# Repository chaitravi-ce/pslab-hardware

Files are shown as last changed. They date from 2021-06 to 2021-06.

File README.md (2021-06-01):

# PSLab Hardware





This is a special branch `diff-img` where the changes made on all four layers relative to the immediate previous board is presented as a diff image.

## Current Layers

<details>
  <summary>External Layers</summary>

| Top | Bottom |
| --- | --- |
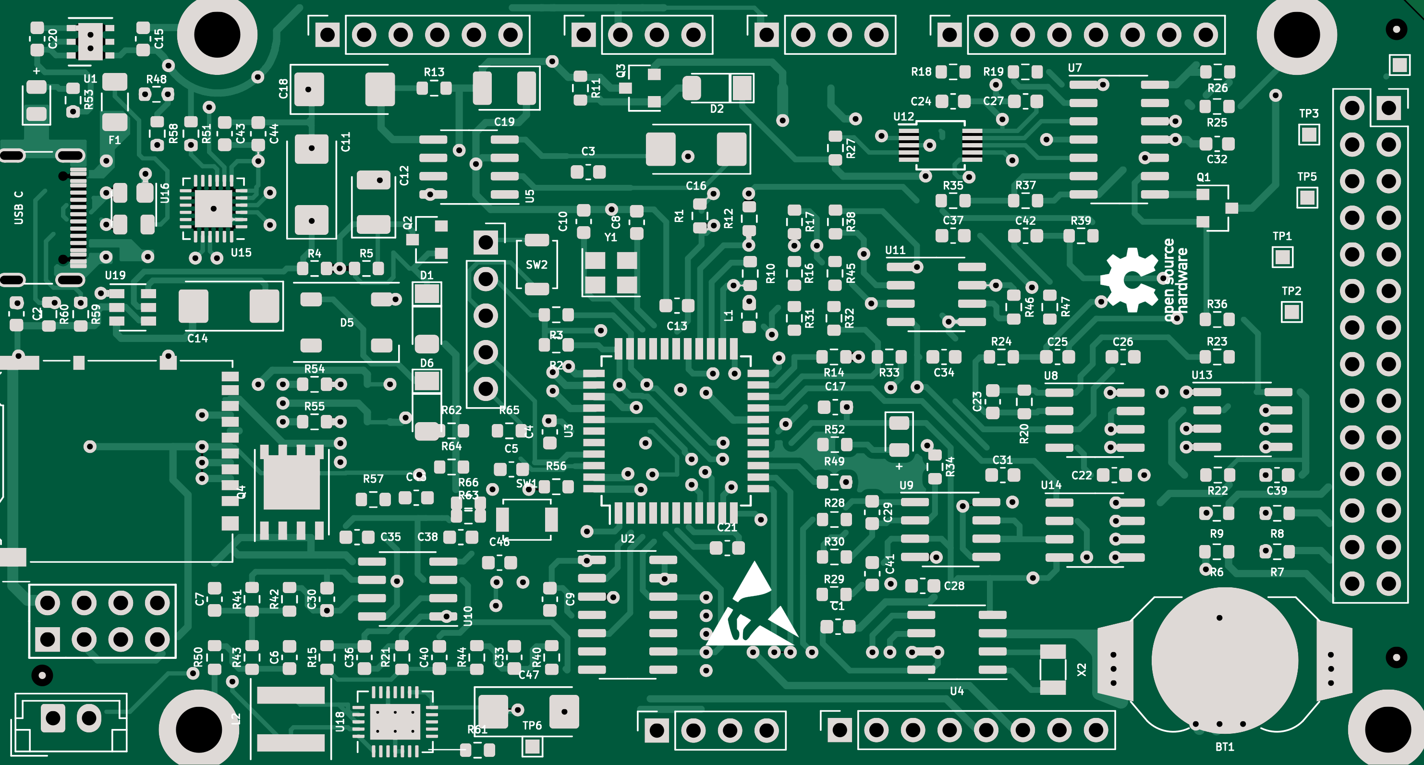
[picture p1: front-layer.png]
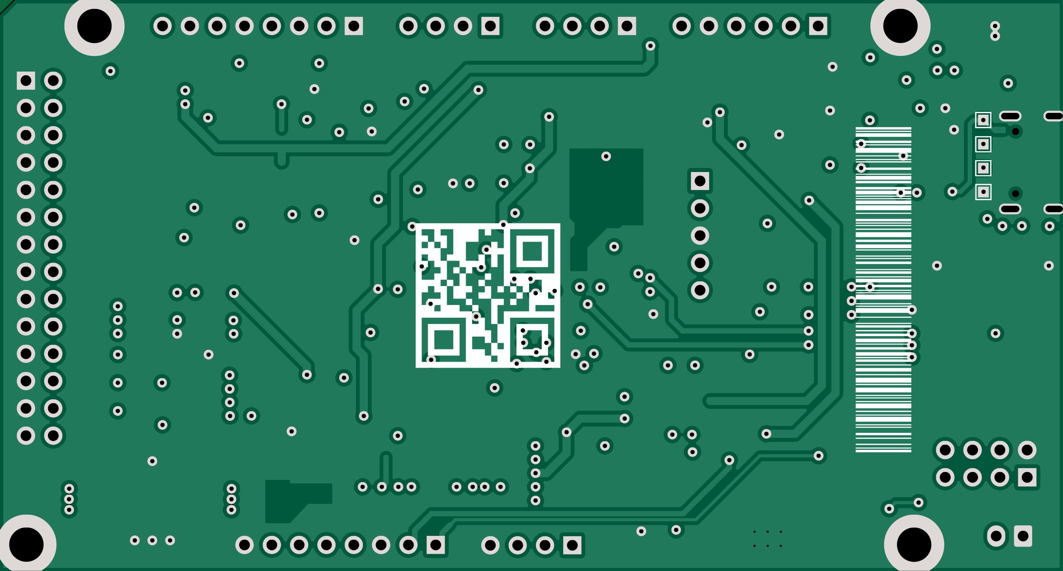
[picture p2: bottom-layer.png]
|  |  |
</details>

<details>
  <summary>Internal Layers</summary>

| Power | Signal |
| ----- | --- |
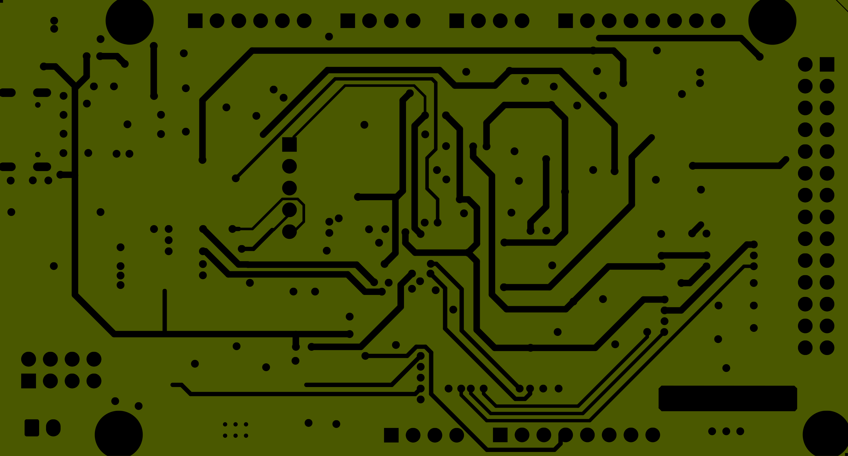
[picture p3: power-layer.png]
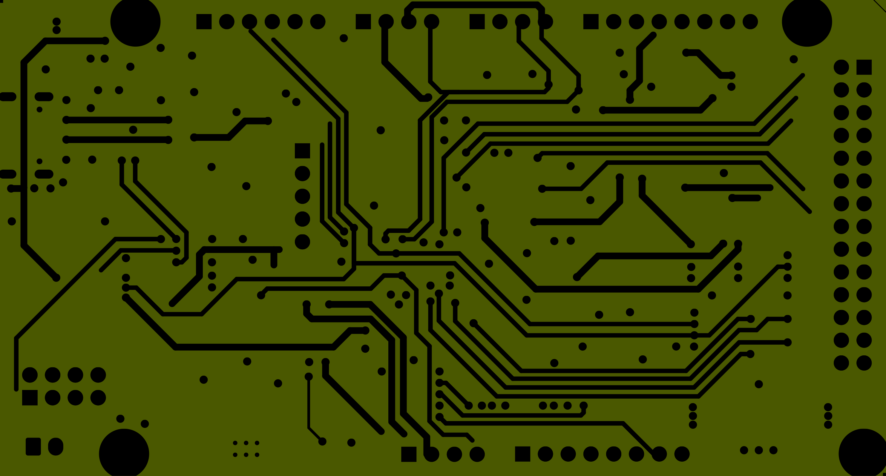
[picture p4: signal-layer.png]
|  |  |
</details>

## Legend

🟥 what the new board has

🟦 what the previous board had

## Schematic Changes
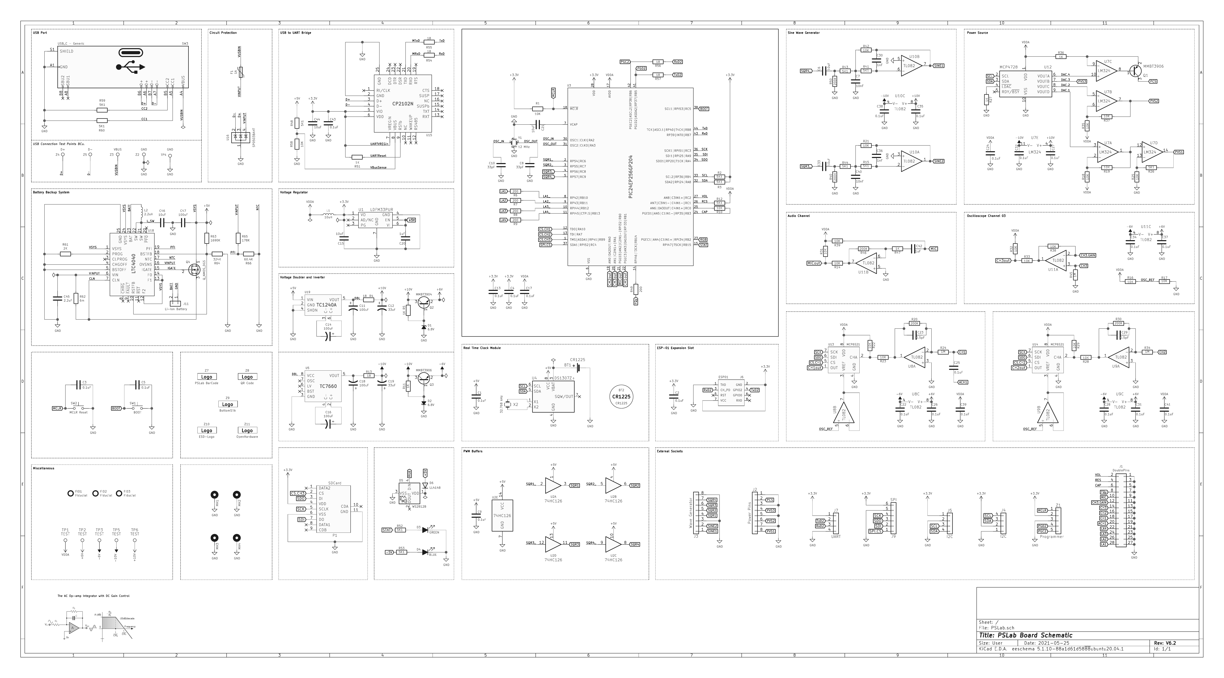
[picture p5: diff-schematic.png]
Schematic


## Board Changes
| Top Layer |
| ---------- |
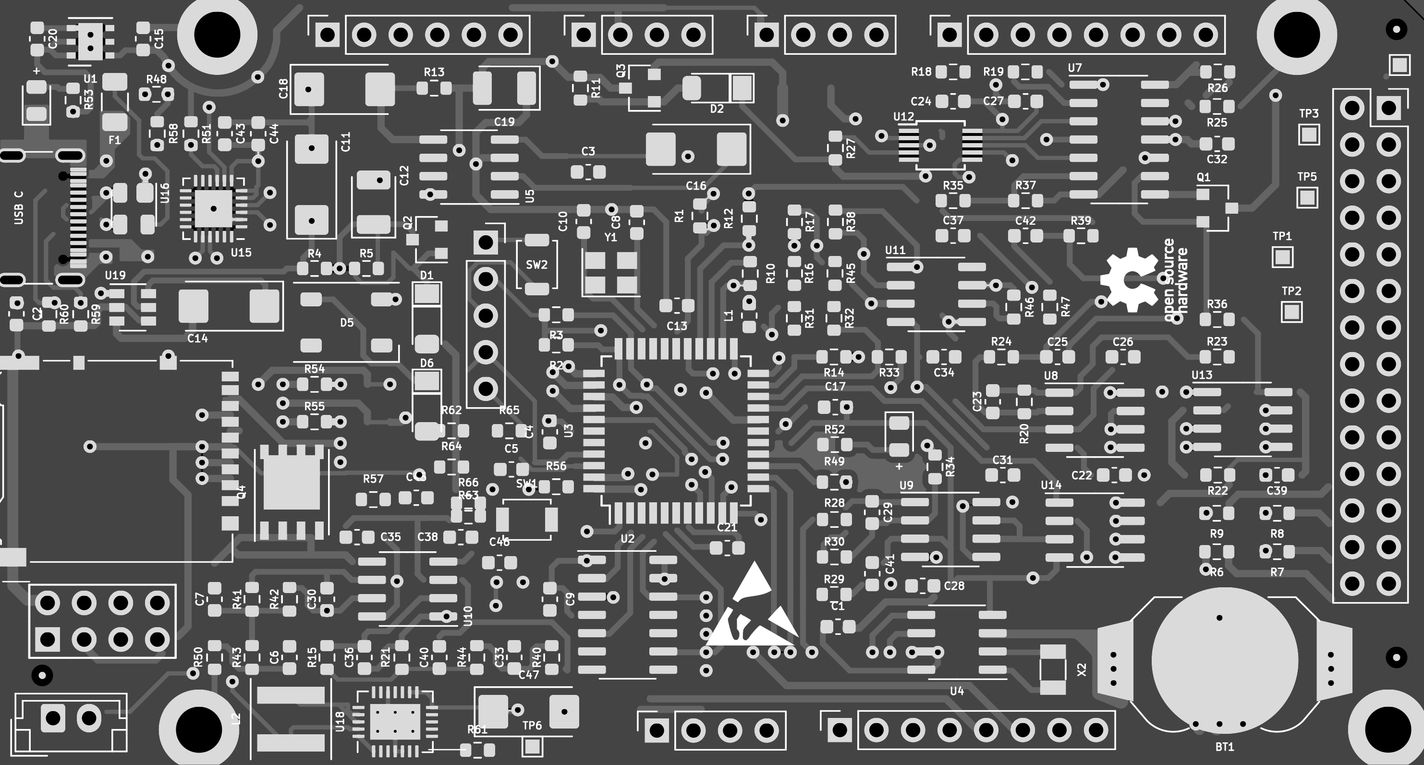
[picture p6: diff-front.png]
Front PCB
|  |

| Bottom Layer |
| --------- |
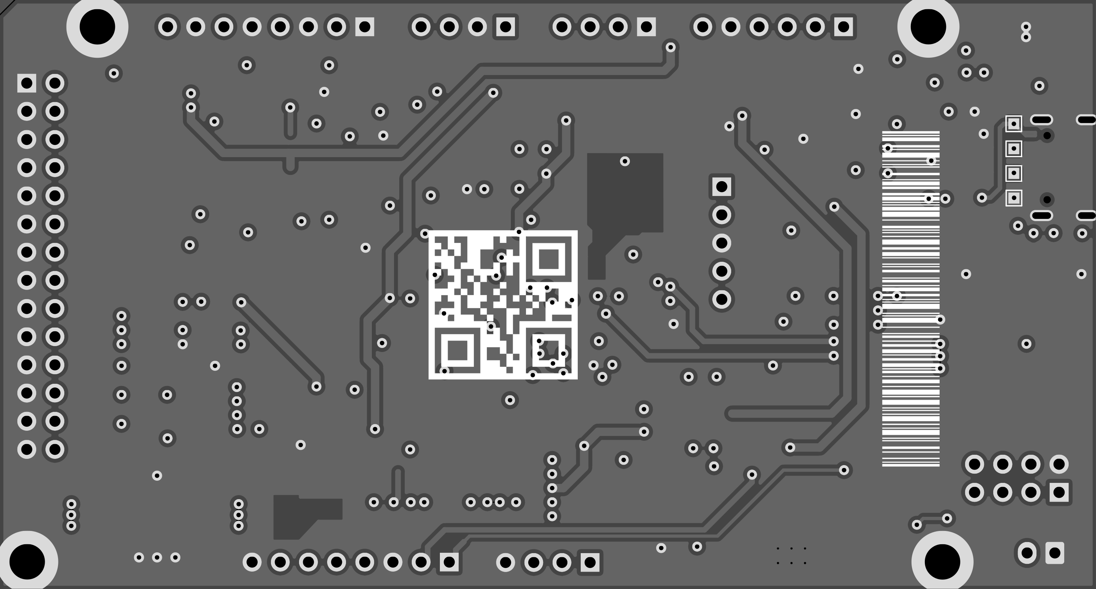
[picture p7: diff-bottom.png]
Rear PCB
|  |

| Power Layer |
| ---------- |
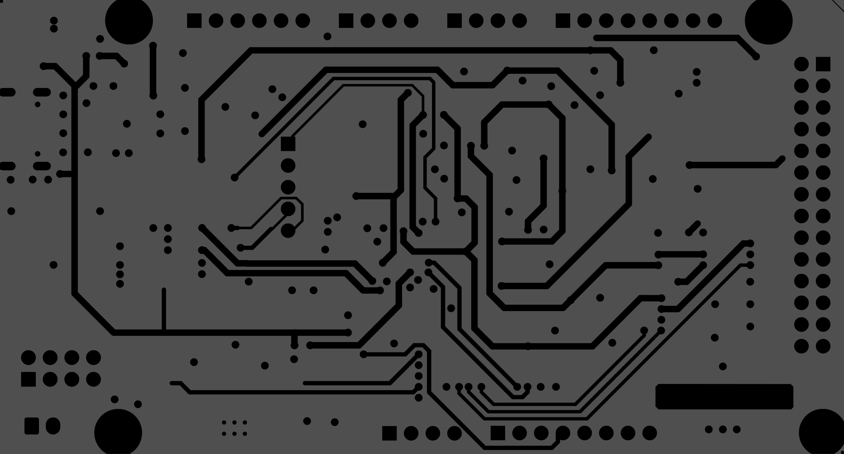
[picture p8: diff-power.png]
Power PCB
|  |

| Signal Layer |
| --------- |
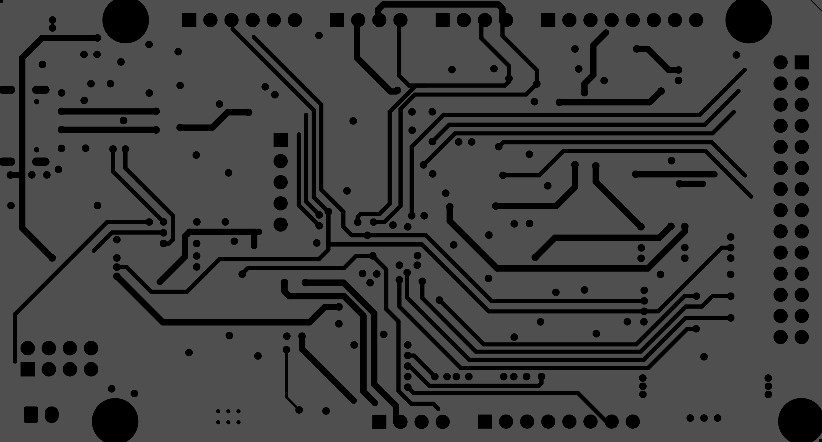
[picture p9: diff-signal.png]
Signal PCB
|  |

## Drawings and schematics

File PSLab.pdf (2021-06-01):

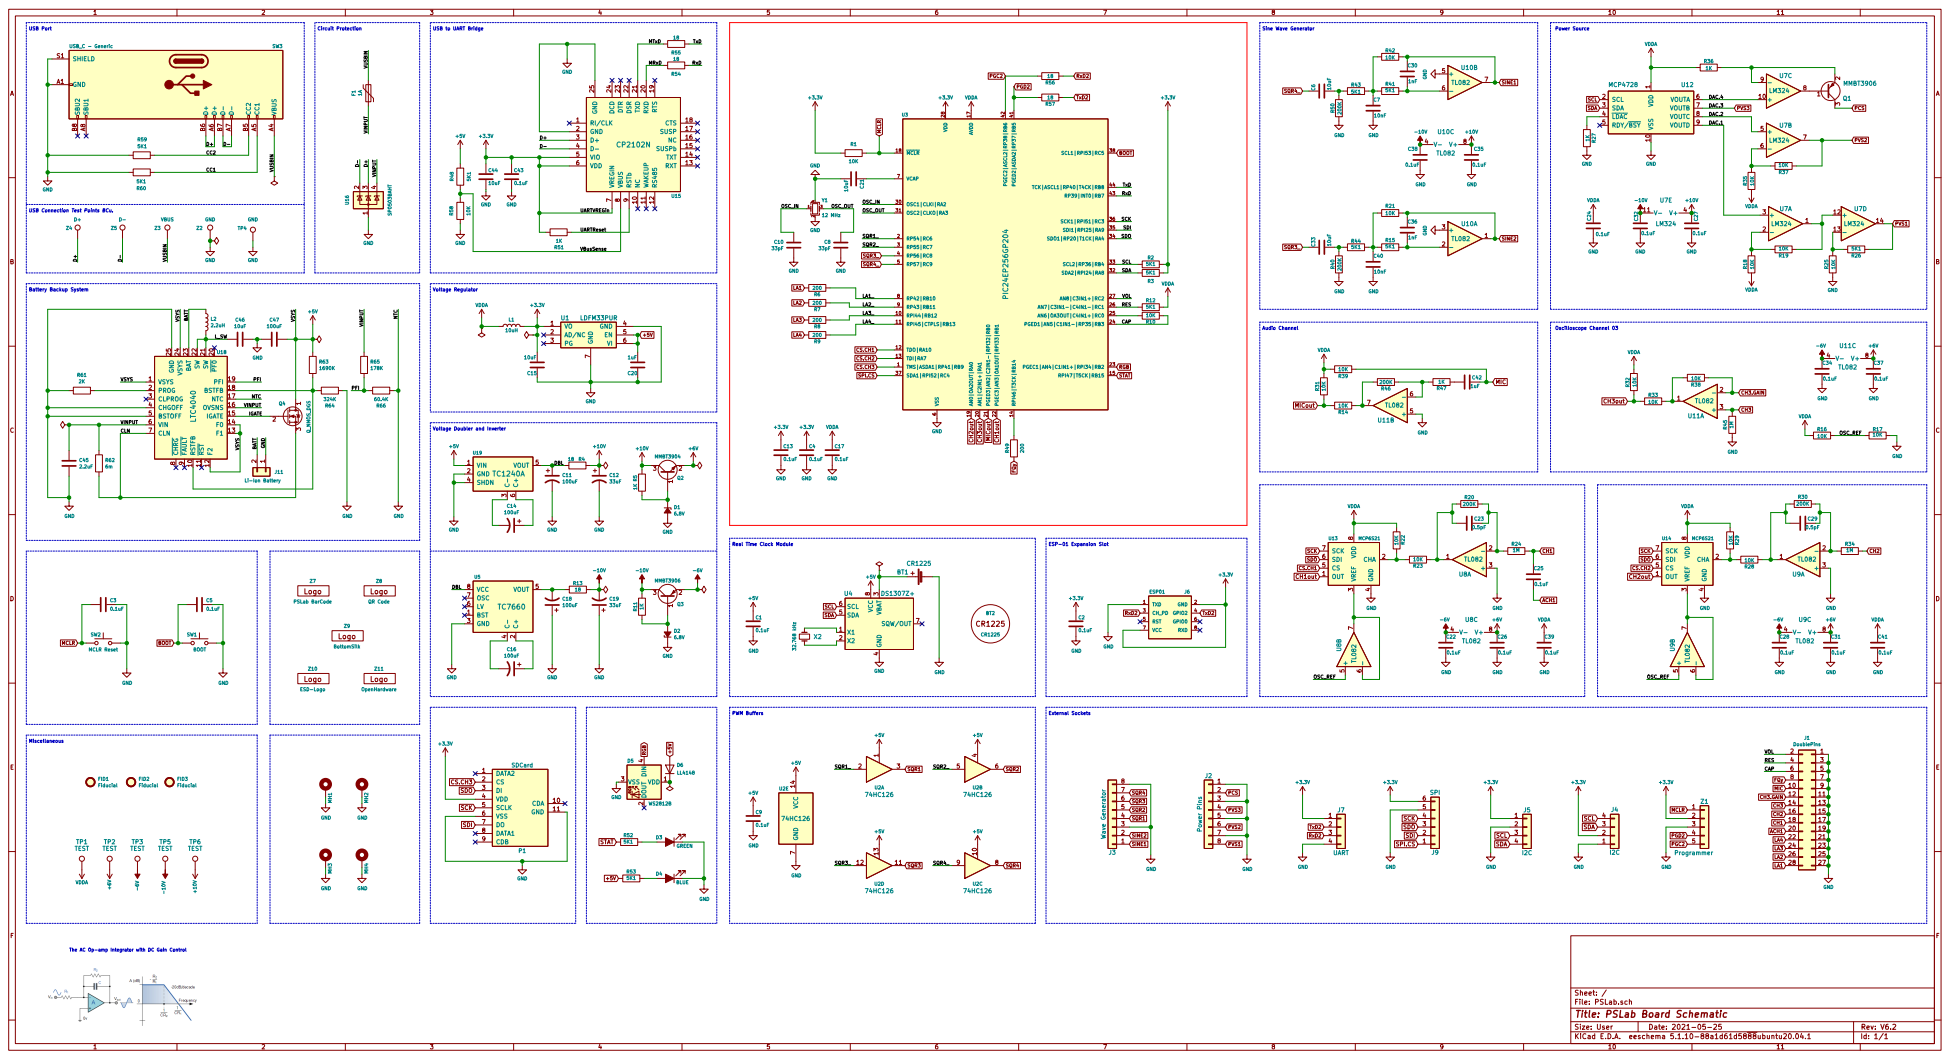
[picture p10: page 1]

Sine Wave Generator Battery Backup System

USB Connection Test Points BCu.

ESP-01 Expansion Slot PWM Buffers

4 SDA 5 SCL 6 SQW/OUT 7 VCC
SDA

The AC Op-amp Integrator with DC Gain Control

File: PSLab.sch Sheet: /
Id: 1/1 Title: PSLab Board Schematic

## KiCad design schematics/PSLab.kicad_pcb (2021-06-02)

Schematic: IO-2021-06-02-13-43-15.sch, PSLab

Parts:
C6, C33: 10u; C_0603
C7, C40: 10nF; C_0603
C22, C24, C25, C26, C27, C28, C31, C32, C34, C35, C37, C38, C39, C41: 0.1u; C_0603
C23, C29: 3p3; C_0603
C30, C36: 1nF; C_0603
C43: 1u; C_0603
J4: Outputs; Pin_Header_Straight_1x12_Pitch2.54mm
J8: Power Pins; Pin_Header_Straight_1x08_Pitch2.54mm
Q1: MMBT3906; SOT-23
R14, R16, R17, R18, R19, R21, R22, R23, R25, R28, R29, R31, R32, R33, R35, R37, R38, R39, R42: 10K; R_0603
R15, R26, R41, R43, R44: 5K1; R_0603
R20, R30, R40, R46, R50: 200K; R_0603
R24, R34, R45: 1M; R_0603
R27, R36, R47: 1K; R_0603
TP1, TP2: TEST; Measurement_Point_Round-SMD-Pad_Small
U7: LM324; SOIC-14_3.9x8.7mm_Pitch1.27mm
U8, U10, U13, U16: TL082; SOIC-8_3.9x4.9mm_Pitch1.27mm
U9: MCP4728; MSOP-10_3x3mm_Pitch0.5mm
U11, U12: 6S21; SOIC-8_3.9x4.9mm_Pitch1.27mm

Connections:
/I/O Processing/DAC1: U7.3 (+), U9.9
/I/O Processing/DAC2: U7.5 (+), U9.8
/I/O Processing/DAC4: U7.10 (+), U9.6
ACH1: C25.2; also elsewhere on the board
AVdd: C24.2, C39.2, C41.2, R16.2, R18.1, R22.2, R29.1, R31.2, R32.2, R35.1, R36.1, R39.2, U9.1, U11.8 (Vdd), U12.8 (Vdd); also elsewhere on the board
CH1: C25.1, R24.1; also elsewhere on the board
CH1out: U11.1 (Vout); also elsewhere on the board
CH2: R34.1; also elsewhere on the board
CH2out: U12.1 (Vout); also elsewhere on the board
CH3: R45.2, U16.3 (+); also elsewhere on the board
CH3.GAIN: R38.1, U16.2 (-); also elsewhere on the board
CH3out: R32.1, R33.1; also elsewhere on the board
CS.CH1: U11.5 (CS); also elsewhere on the board
CS.CH2: U12.5 (CS); also elsewhere on the board
MICout: R14.1, R31.1; also elsewhere on the board
unnamed: C6.2, R43.1, R50.1
unnamed: C7.1, R41.2, R42.1, R43.2
unnamed: C23.1, R20.1, R23.2, U8.1
unnamed: C23.2, R20.2, R24.2, U8.2 (-)
unnamed: C29.1, R28.1, R30.1, U10.1
unnamed: C29.2, R30.2, R34.2, U10.2 (-)
unnamed: C30.2, R41.1, U13.6 (-)
unnamed: C33.2, R40.1, R44.1
unnamed: C36.2, R15.1, U13.2 (-)
unnamed: C40.1, R15.2, R21.2, R44.2
unnamed: Q1.1 (B), U7.8
unnamed: Q1.2 (E), R36.2, U7.9 (-)
unnamed: R14.2, R46.2, U16.7
unnamed: R16.1, R17.1, U8.5 (+), U10.5 (+)
unnamed: R18.2, R19.1, U7.2 (-)
unnamed: R19.2, U7.1, U7.12 (+)
unnamed: R22.1, R23.1, U11.2 (CH0)
unnamed: R25.2, R26.1, U7.13 (-)
unnamed: R27.1, U9.4
unnamed: R28.2, R29.2, U12.2 (CH0)
unnamed: R33.2, R38.2, U16.1
unnamed: R35.2, R37.1, U7.6 (-)
unnamed: R46.1, R47.1, U16.6 (-)
unnamed: U10.6 (-), U10.7, U12.3 (Vref)
unnamed: U8.6 (-), U8.7, U11.3 (Vref)
PCS: J8.7, Q1.3 (C)
PVS1: J8.1, R26.2, U7.14
PVS2: J8.3, R37.2, U7.7
PVS3: J8.5, U9.7
SCK: U11.7 (SCK), U12.7 (SCK); also elsewhere on the board
SCL: U9.2; also elsewhere on the board
SDA: U9.3; also elsewhere on the board
SDO: U11.6 (SDI), U12.6 (SDI); also elsewhere on the board
SINE1: C30.1, J4.2, R42.2, U13.7
SINE2: C36.1, J4.4, R21.1, U13.1
SQ3: C33.1; also elsewhere on the board
SQ4: C6.1; also elsewhere on the board
SQR1: J4.6; also elsewhere on the board
SQR2: J4.8; also elsewhere on the board
SQR3: J4.10; also elsewhere on the board
SQR4: J4.12; also elsewhere on the board
V+: C27.1, C35.2, TP2.1, U7.4 (V+), U13.8 (V+); also elsewhere on the board
V-: C32.1, C38.2, TP1.1, U7.11 (V-), U13.4 (V-); also elsewhere on the board
VR+: C26.2, C31.2, C37.2, U8.8 (V+), U10.8 (V+), U16.8 (V+); also elsewhere on the board
VR-: C22.2, C28.2, C34.2, U8.4 (V-), U10.4 (V-), U16.4 (V-); also elsewhere on the board

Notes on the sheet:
4-Channel DAC. Used for PV1(+/-5V) , PV2(+/-3.3V) , PV3 (0-3.3V) , PCS (0-2mA) And associated analog circuitry
Sine Wave generator filters (Simulated for 5Hz to 5KHz at Okawa-Denshi)
Signal Processing
Expansion

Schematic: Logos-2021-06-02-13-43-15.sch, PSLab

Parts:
S1: OpenHardware; OSHW-Logo2_7.3x6mm_SilkScreen
S2: PSLab_Logo
S3: ESD-Logo; ESD-Logo_6.6x6mm_SilkScreen
S4: App_Barcode; Barcode
S5, S8: OpnTec_Logo
S6: FOSSASIA_Logo_S; FOSSASIA_Logo
S7: PSL_Logo
S9: QR_Code; Website_QR
S10: FOSSASIA_Logo_L; FOSSASIA_LogoL

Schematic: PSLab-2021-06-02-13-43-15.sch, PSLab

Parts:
C1, C2, C4, C5, C9, C13, C17: 0.1u; C_0603
C3, C8, C10, C43: 33p; C_0603
C11, C14, C16, C18: 100u; CP_Tantalum_Case-C_EIA-6032-28_Reflow
C12, C19: 33u; CP_Tantalum_Case-B_EIA-3528-21_Reflow
C15, C21: 10u; C_0603
C20: 1u; C_0603
CON1: USB-MINI-B; USB_Micro-B
D1, D2: 6V8; D_MiniMELF
D3, D4: LED; LED_0805
F1: 0.5A; Fuse_SMD1206_Reflow
J1: Programmer; Pin_Header_Straight_1x06_Pitch2.54mm
J2: DoublePins; Pin_Header_Straight_2x14_Pitch2.54mm
J3: LA; Pin_Header_Straight_1x04_Pitch2.54mm
J5: Bluetooth; Pin_Header_Straight_1x06_Pitch2.54mm
J6: I2C-1; Pin_Header_Straight_1x04_Pitch2.54mm
J7: UART/ESP; Pin_Header_Straight_1x07_Pitch2.54mm
J10: GND; Measurement_Point_Square-SMD-Pad_Small
J11: Vbus; Measurement_Point_Square-SMD-Pad_Small
J13: D+; Measurement_Point_Square-SMD-Pad_Small
J14: D-; Measurement_Point_Square-SMD-Pad_Small
J16: I2C-2; Pin_Header_Straight_1x04_Pitch2.54mm
L1: 10uH; L_0603
MH1, MH2, MH3, MH4: M; MountingHole_3.2mm_M3_DIN965_Pad
Q2: MMBT3904; SOT-23
Q3: MMBT3906; SOT-23
R1, R2, R3, R10: 10K; R_0603
R4, R13, R54, R55, R56, R57: 18; R_0603
R5, R11: 1K; R_0603
R6, R7, R8, R9, R49: 200; R_0603
R12, R48, R52, R53: 5K1; R_0603
TP3, TP4: TEST; Measurement_Point_Round-SMD-Pad_Small
TP5, TP6, TP7: Fiducial; Fiducial_0.5mm_Dia_1mm_Outer
U1: MCP2200; SOIC-20W_7.5x12.8mm_Pitch1.27mm
U2: 74HC126; SOIC-14_3.9x8.7mm_Pitch1.27mm
U3: PIC24EP256GP204; TQFP-44_10x10mm_Pitch0.8mm
U4: TC1240A; SOT-23-6
U5: 7660; SOIC-8_3.9x4.9mm_Pitch1.27mm
U6: LM1117-3.3; SOT-223
U15: ESP8266; Hopref_RFM9XW_SMD
X1: 12MHz; Crystal_SMD_5032-2pin_5.0x3.2mm
Y1: 12MHz; Crystal_SMD_5032-2pin_5.0x3.2mm

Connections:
+5V: C9.2, C20.2, F1.2, J5.2, J7.6, R53.2, TP3.1, U2.1 (1EN), U2.4 (2EN), U2.10 (3EN), U2.13 (4EN), U2.14 (VCC), U4.1 (Vin), U6.3
/D+: CON1.3 (D+), J13.1, U1.19 (D+)
/D-: CON1.2 (D-), J14.1, U1.18 (D-)
/ERxD: R56.1, U15.15 (RXD)
/ESPROG: J7.2, U15.12 (GP0)
/ETxD: R57.1, U15.16 (TXD)
/ID1: R6.2, U3.8 (RB10/RP42)
/ID2: R7.2, U3.9 (RP43/RB11)
/ID3: R8.2, U3.10 (RPI44/RB12)
/ID4: R9.2, U3.11 (RPI45/RB13)
/MRxD: R54.2, U1.12 (RX)
/MTxD: R55.2, U1.10 (TX)
ACH1: J2.19; also elsewhere on the board
AN8: J2.1, U3.27 (RC2/AN8)
AVdd: C17.2, L1.2, R12.1, U3.17 (AVdd); also elsewhere on the board
CAP: J2.5, R10.1, U3.24 (RB3/RP35/AN5)
CH1: J2.17; also elsewhere on the board
CH1out: U3.22 (AN3/RB1); also elsewhere on the board
CH2: J2.15; also elsewhere on the board
CH2out: U3.19 (AN0/RA0); also elsewhere on the board
CH3: J2.13; also elsewhere on the board
CH3.GAIN: J2.11; also elsewhere on the board
CH3out: U3.20 (AN1/RA1); also elsewhere on the board
CS.CH1: U3.12 (TDO/RA10); also elsewhere on the board
CS.CH2: U3.13 (TDI/RA7); also elsewhere on the board
FCin: J2.7, R49.2
IDA: J2.27, J3.4, R6.1
IDB: J2.25, J3.3, R7.1
IDC: J2.23, J3.2, R8.1
IDD: J2.21, J3.1, R9.1
MCLR: J1.1, R1.2, U3.18 (~MCLR)
MICout: U3.21 (AN2/RB0); also elsewhere on the board
unnamed: C8.2, U3.31 (OSC2), X1.1
unnamed: C10.2, U3.30 (OSC1), X1.2
unnamed: C11.1, R4.2, U4.5 (Vo), U5.8 (Vcc)
unnamed: C14.1, U4.6 (C+)
unnamed: C14.2, U4.3 (C-)
unnamed: C16.1, U5.2 (C+)
unnamed: C16.2, U5.4 (C-)
unnamed: C18.2, R13.2, U5.5 (Vout)
unnamed: C21.2, U3.7 (Vcap)
unnamed: CON1.1 (VBUS), F1.1, J11.1
unnamed: D1.2 (K), Q2.1 (B), R5.2
unnamed: D2.1 (A), Q3.1 (B), R11.1
unnamed: D3.2, R52.1
unnamed: D4.2, R53.1
unnamed: R10.2, U3.25 (RC0/AN6)
unnamed: R48.2, U1.4 (~RST)
unnamed: R49.1, U3.14 (RB14/RPI46)
unnamed: U2.2 (1A), U3.2 (RC6/RP54)
unnamed: U2.5 (2A), U3.3 (RC7/RP55)
OS1: C3.1, U1.2 (OSC1), Y1.1
PGC2: J1.5, U3.42 (PGEC2)
PGD2: J1.4, U3.41 (PGED2)
RP147: R52.2, U3.15 (RB15/RPI47)
RxD: J5.5, J7.3, R54.1, R56.2, U3.43 (RP39/INT)/RB7)
SCK: U3.36 (SCK1/RPI51/RC3); also elsewhere on the board
SCL: J6.3, J16.3, R2.1, U3.33 (SCL2); also elsewhere on the board
SDA: J6.4, J16.4, R3.1, U3.32 (SDA2/RA8); also elsewhere on the board
SDO: U3.34 (CVref/SD01); also elsewhere on the board
SEN: J2.3, R12.2, U3.26 (RC1/AN7)
SQ3: U2.12 (4A), U3.4 (RC8/RP56); also elsewhere on the board
SQ4: U2.9 (3A), U3.5 (RC9/RP57); also elsewhere on the board
SQR1: U2.3 (1Y); also elsewhere on the board
SQR2: U2.6 (2Y); also elsewhere on the board
SQR3: U2.11 (4Y); also elsewhere on the board
SQR4: U2.8 (3Y); also elsewhere on the board
TxD: J5.4, J7.4, R55.1, R57.2, U3.44 (RP40/RB8)
V+: C12.1, Q2.3 (C), R4.1, R5.1; also elsewhere on the board
V-: C19.2, Q3.3 (C), R11.2, R13.1; also elsewhere on the board
VR+: Q2.2 (E); also elsewhere on the board
VR-: Q3.2 (E); also elsewhere on the board
Vdd: C1.1, C2.2, C4.1, C5.1, C13.2, C15.2, J1.2, J6.2, J7.7, J16.2, L1.1, R1.1, R2.2, R3.2, R48.1, U1.1 (Vdd), U1.17 (Vusb), U3.28 (Vdd), U3.40 (Vdd), U6.2, U6.4, U15.3 (CH_PD), U15.8 (Vcc), U15.11 (GP2)

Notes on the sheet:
For WiFi Option
USB & Power Connector , USB-UART Convertor
Programming Header
Bipolar Supply Generators & Filters
Status LED
Mounting Holes
Expansions
I/O Processing
Regulator
Logic Analyzer
Bluetooth

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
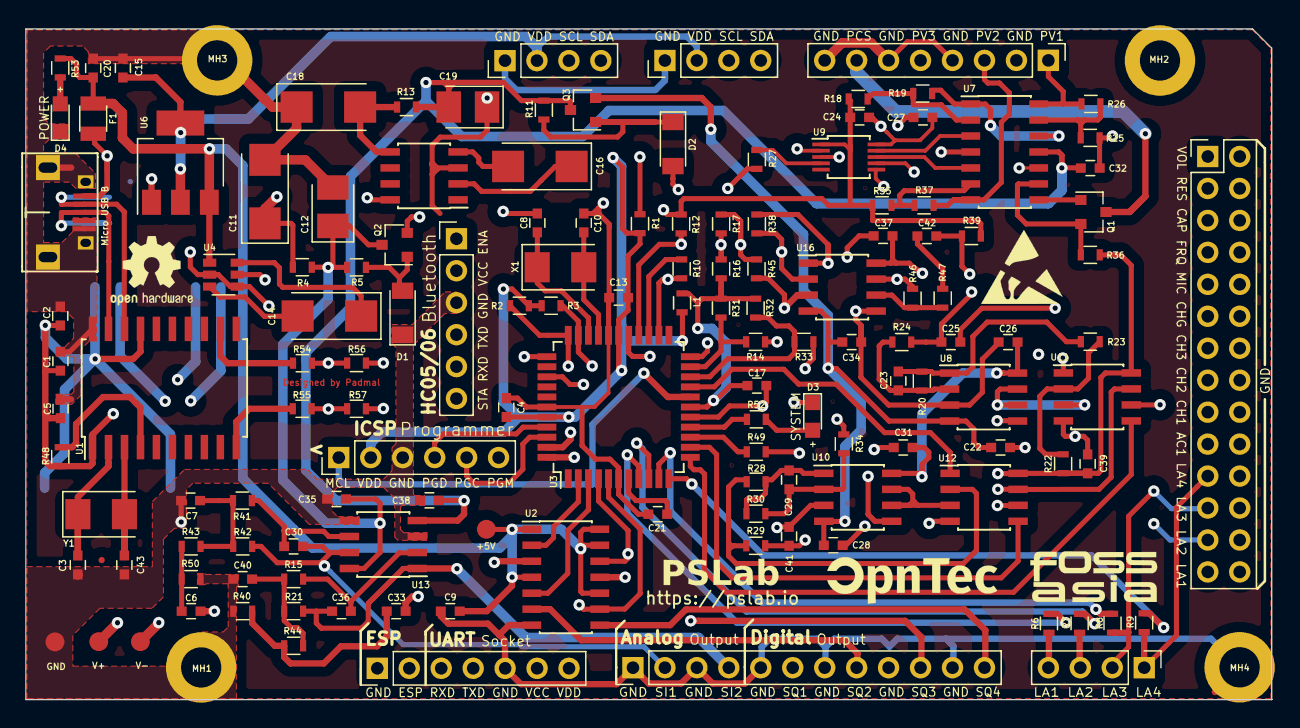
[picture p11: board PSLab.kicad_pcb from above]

Board: 4 copper layers, 99.0 x 53.3 mm, 158 parts (0 on the bottom side), 111 nets.

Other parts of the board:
C42: 1u; C_0603

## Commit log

2021-06-01 chore: updating board diff images
2021-06-02 Optimized Routing and Fixed DRC
    [IO-2021-06-02-13-43-15.sch, Logos-2021-06-02-13-43-15.sch, PSLab-2021-06-02-13-43-15.sch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]
2021-06-02 Optimized Routing
    [PSLab.kicad_pcb]
